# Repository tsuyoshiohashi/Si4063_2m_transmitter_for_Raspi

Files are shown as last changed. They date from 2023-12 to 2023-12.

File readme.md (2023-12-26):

# Si4063 2m transmitter for Raspi

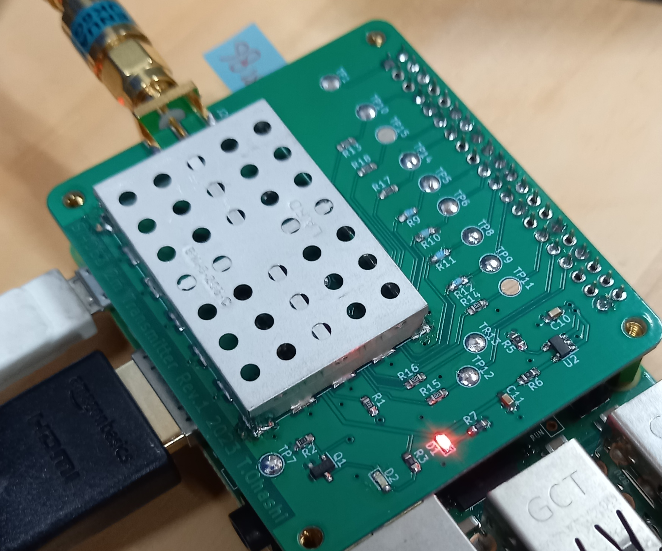
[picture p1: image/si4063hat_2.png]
Si4063_hat si4063_hat


Transmit a modulated wave in the 144Mhz band using RaspberryPi and an expansion board (si4063 2m radio hat, homemade, see hat directory).

・Frequency can be set from 144 to 146MHz

・The maximum output is 0.1W (20dBm) and can be set in 128 steps.

・CW (Continuous wave), OOK, FSK modulation is possible

・If you want to attach an antenna and actually emit radio waves, you will need an amateur radio license/qualification.

. When operating, be sure to terminate the SMA terminal (J2: RF output terminal). Otherwise, it may break.

# Environment where operation has been confirmed
Raspi3B+　Raspberry Pi OS(bookworm)

You need to install pigpio.

# HAT configuration and operation
As the title says, we use Silicon Labs' Si4063-C.

The SPI is controlled from the Raspi, but it is controlled by itself via GPIO, so there is no need to configure the SPI of the Raspi.
If SPI0 is enabled, please disable it. (Used as GPIO)

Si4063 operates in Direct Async Mode.

Transmission data is passed from the Raspi's GPIO to the Si4063's GPIO, and is transmitted at the same timing without going through the FIFO.

While transmitting, LED2 lights up as an indicator.

# Software
## si4063.py

You can perform simple sending operations by running it from the command line.

````
$ python si4063.py
````

If there are no arguments, display simple help and exit.
The arguments are as follows.

### -c (seconds)
Transmits unmodulated waves for the specified number of seconds. (10 seconds if not specified)
It is used to measure output magnitude, spurious, etc.

The transmission frequency is 144.05MHz by default. (Can be set with variables)

### -f
Transmits FSK modulated wave for about 10 seconds.

The data is 10101010....
The data rate is approximately 1000bps.
The frequency deviation is 8kHz.
These can be set with parameters.

The IC specifications support data rates up to 1Mbps.
I think high-speed communication is possible if you create an accurate baud rate using a timer interrupt. (It's a little difficult in python...)

### -o
Transmits OOK modulated wave for about 10 seconds.

The data is 10101010....
The data rate is approximately 1000bps.
Like FSK, it can be set with parameters.

Please note that si4063const.py is a parameter file. Please put it in the same directory.

## Main methods
si4063.py can be used by importing it into a python program as a module. (This is the original usage)

The main methods are shown below.

### reset()
Reset si4063.
Execute once after turning on the power.

### power_up()
Boot si4063. Use in the order of reset → power_up.

### part_info()
Get the chip number.
````
count, chip_no = si4063.part_info()
````
count: Number of times it took to retrieve (usually it can be read in one time, but if it is too many times, something is happening)

chip_no: Chip number (0x4063)

### set_radio_frequency(frequency)
Set the transmission frequency. The unit is Hz.
There may be an discrepancies of about 2Hz depending on the resolution of the synthesizer.

### set_modem_freq_offset(freq_offset)
Gives an offset to the transmit frequency.
This corrects the error in the crystal's oscillation frequency, but the value seems to vary depending on the modulation method.
The unit is Hz.

### set_pa_pwr_lvl(pwr_lvl)
Set the transmit power. Specify a value between 0x0 and 0x7f.
A graph of setting values and output can be found in Figure 8 of the si4063-C data sheet.

### setup(mod_type, freq_dev)
Configure the IC register settings and set the modulation method.

Specify either MOD_TYPE_OOK, MOD_TYPE_FSK, or MOD_TYPE_CW.

For FSK, the frequency deviation can be specified in Hz.

### start_tx()
Start sending.

### stop_tx()
Stop sending. The internal state is READY.

### tx_data(data)
Set the sending data data(0|1).
In the sending state, it will be reflected immediately.

### get_adc_reading()
Measures the IC power supply voltage and temperature.

````
temp, voltage = si4063.get_adc_reading()
````

The units are °C and V.

Please note that si4063Cconst.py is a parameter file. Please put it in the same directory.

## radio_morse.py

This is a sample app that sends Morse code.
Import and use si4063.py.

Start it by specifying the wpm number as an argument on the command line.

````
$ python radio_morse.py wpm
````

You will be asked to enter a character string, so please enter an alphanumeric character string.

Morse code '.' and '-' are displayed on the console and sent.

Please note that wpm is limited to 5 to 30.

Have A Fun!

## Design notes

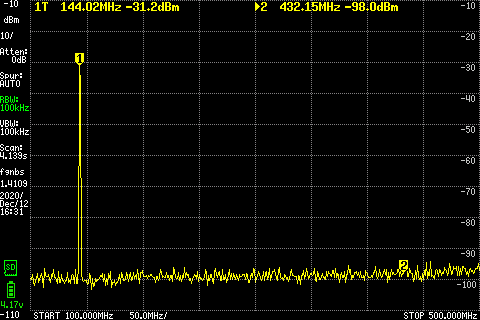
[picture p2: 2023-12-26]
image/si4063_harmonics.bmp

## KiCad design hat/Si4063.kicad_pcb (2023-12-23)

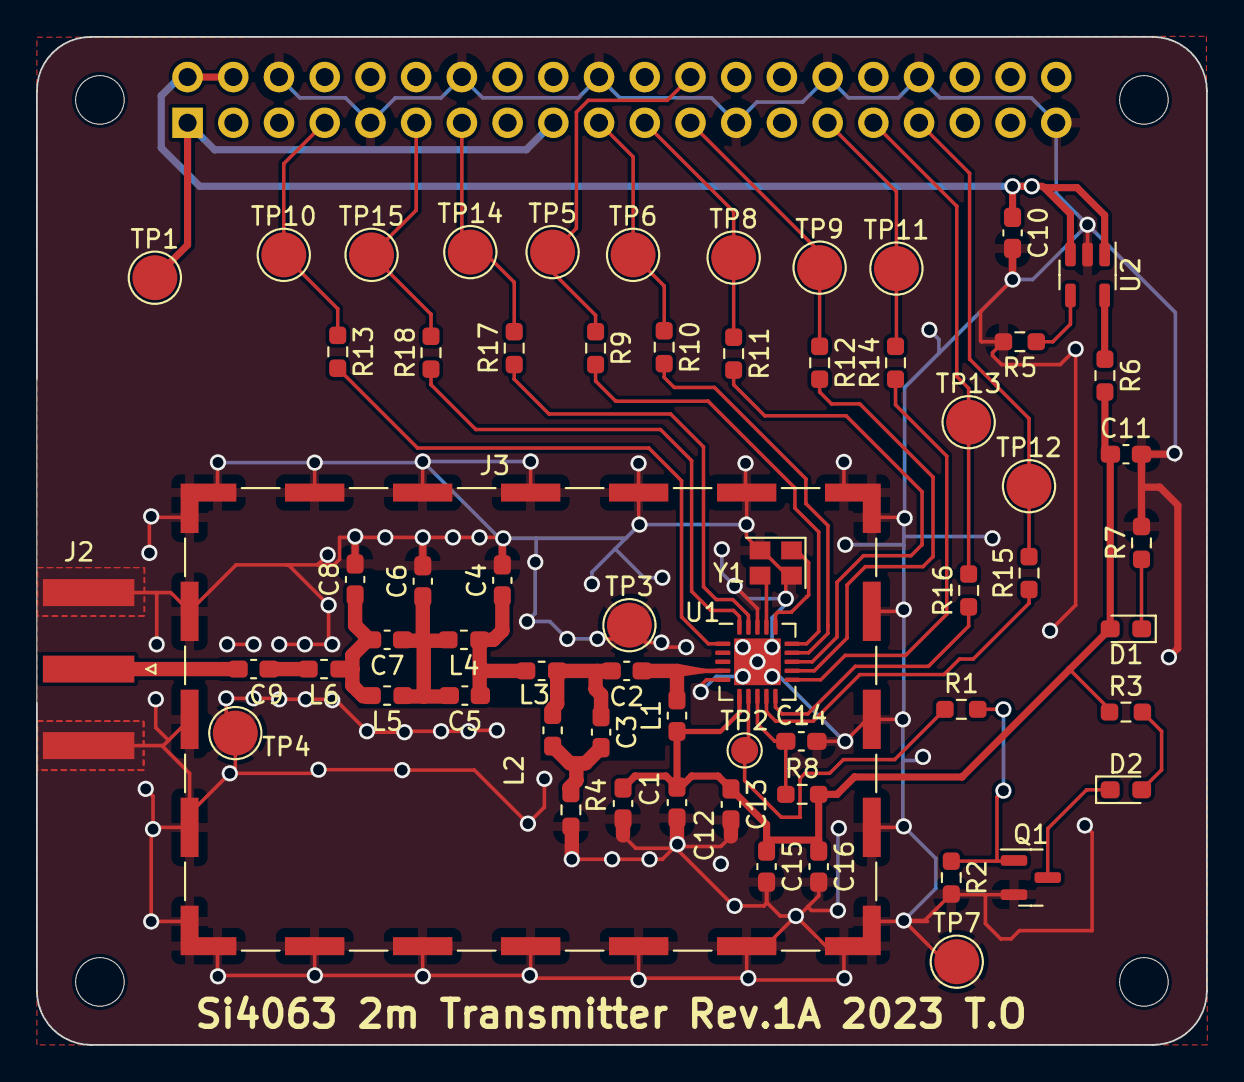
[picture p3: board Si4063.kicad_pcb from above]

Board: 2 copper layers, 65.0 x 56.0 mm, 68 parts (1 on the bottom side), 42 nets.

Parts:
C7: 2.4pF; C_0603_1608Metric_Pad1.08x0.95mm_HandSolder
C10, C11: 105; C_0603_1608Metric_Pad1.08x0.95mm_HandSolder
C12: 101; C_0603_1608Metric_Pad1.08x0.95mm_HandSolder
C13: 471; C_0603_1608Metric_Pad1.08x0.95mm_HandSolder
C14, C15: 104; C_0603_1608Metric_Pad1.08x0.95mm_HandSolder
C16: 225; C_0603_1608Metric_Pad1.08x0.95mm_HandSolder
C?: 471; C_0603_1608Metric_Pad1.08x0.95mm_HandSolder
C?#2, C?#3: 22pF; C_0603_1608Metric_Pad1.08x0.95mm_HandSolder
C?#4, C?#5: 13pF; C_0603_1608Metric_Pad1.08x0.95mm_HandSolder
C?#6, C?#8: 470pF; C_0603_1608Metric_Pad1.08x0.95mm_HandSolder
C?#7: 3.6pF; C_0603_1608Metric_Pad1.08x0.95mm_HandSolder
D1: PWR; D_0603_1608Metric_Pad1.05x0.95mm_HandSolder
D?: LED; D_0603_1608Metric_Pad1.05x0.95mm_HandSolder
J1: GPIO; PinSocket_2x20_P2.54mm_Vertical
J2: Conn_Coaxial; SMA_Amphenol_132289_EdgeMount
J3: RFShield_TwoPieces; Laird_Technologies_BMI-S-205-F_38.10x25.40mm
L?: 100nH; L_0603_1608Metric_Pad1.05x0.95mm_HandSolder
L?#2: 390nH; L_0603_1608Metric_Pad1.05x0.95mm_HandSolder
L?#3, L?#6: 56nH; L_0603_1608Metric_Pad1.05x0.95mm_HandSolder
L?#4: 82nH; L_0603_1608Metric_Pad1.05x0.95mm_HandSolder
L?#5: 33nH; L_0603_1608Metric_Pad1.05x0.95mm_HandSolder
MH1, MH2, MH3, MH4: MountingHole_2.7mm_M2.5
Q?: Q_NMOS_GSD; SOT-23
R5, R6: 0; R_0603_1608Metric_Pad0.98x0.95mm_HandSolder
R7: 391; R_0603_1608Metric_Pad0.98x0.95mm_HandSolder
R8: 4R7; R_0603_1608Metric_Pad0.98x0.95mm_HandSolder
R9, R13, R14, R15, R16, R17, R18: 47; R_0603_1608Metric_Pad0.98x0.95mm_HandSolder
R10, R11, R12: 39; R_0603_1608Metric_Pad0.98x0.95mm_HandSolder
R?: 2.2k; R_0603_1608Metric_Pad0.98x0.95mm_HandSolder
R?#2: 10k; R_0603_1608Metric_Pad0.98x0.95mm_HandSolder
R?#3: 271; R_0603_1608Metric_Pad0.98x0.95mm_HandSolder
R?#4: 50; R_0603_1608Metric_Pad0.98x0.95mm_HandSolder
TP1: 3.3V; TestPoint_Pad_D2.5mm
TP3, TP4, TP7: GND; TestPoint_Pad_D2.5mm
TP5: nSEL; TestPoint_Pad_D2.5mm
TP6: SDI; TestPoint_Pad_D2.5mm
TP8: SDO; TestPoint_Pad_D2.5mm
TP9: SCLK; TestPoint_Pad_D2.5mm
TP10: SDN; TestPoint_Pad_D2.5mm
TP11: nIRQ; TestPoint_Pad_D2.5mm
TP12: GPIO0; TestPoint_Pad_D2.5mm
TP13: GPIO1; TestPoint_Pad_D2.5mm
TP14: GPIO2; TestPoint_Pad_D2.5mm
TP15: GPIO3; TestPoint_Pad_D2.5mm
TP?: TestPoint; TestPoint_Pad_D1.5mm
U1: Si4063; QFN-20-1EP_4x4mm_P0.5mm_EP2.6x2.6mm
U2: MIC5365-3.3YD5; SOT-23-5
Y1: 30MHz; Crystal_SMD_2520-4Pin_2.5x2.0mm

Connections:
+3.3VA: C11.1, C12.1, C13.1, C15.1, C16.1, C?.1, D1.2 (A), L?#2.1, R6.2, R8.2, R?#3.1, U1.6 (VDD)
+5V: C10.1, J1.2, J1.4, U2.1 (VIN), U2.3 (EN)
/GPIO4_SDN: J1.7, R13.1, TP10.1
/GPIO5_nIRQ: J1.29, R14.2, TP11.1
/GPIO6_GPIO1: J1.31, R16.2, TP13.1
/GPIO13_GPIO0: J1.33, R15.2, TP12.1
/GPIO17_GPIO3: J1.11, R18.2, TP15.1
/GPIO27_GPIO2: J1.13, R17.2, TP14.1
/SPI0.CE0: J1.24, R9.1, TP5.1
/SPI0.MISO: J1.21, R11.1, TP8.1
/SPI0.MOSI: J1.19, R10.1, TP6.1
/SPI0.SCLK: J1.23, R12.1, TP9.1
/power/LED_3.3: D1.1 (K), R7.1
/rf/RF_OUT: C?#8.2, J2.1 (In)
GND: C10.2, C11.2, C12.2, C13.2, C14.2, C15.2, C16.2, C?.2, C?#2.2, C?#3.2, C?#4.2, J1.6, J1.9, J1.14, J1.20, J1.25, J1.30, J1.34, J1.39, J2.2 (Ext), J3.1 (Shield), Q?.2 (S), R5.2, R7.2, R?#2.2, R?#4.2, TP3.1, TP4.1, TP7.1, U1.5 (NC), U1.18 (GND), U1.21 (PADDLE), U2.2 (GND), Y1.2, Y1.4
unnamed: C?#6.1, L?#2.2, U1.4 (TX)
unnamed: C?#5.1, C?#6.2, L?.1, L?#3.1
unnamed: C?#5.2, L?.2, R?#4.1
unnamed: C?#3.1, C?#7.1, L?#3.2, L?#4.1
unnamed: C7.1, C?#2.1, C?#7.2, L?#4.2, L?#6.1
unnamed: C7.2, C?#4.1, L?#5.1, L?#6.2
unnamed: C?#8.1, L?#5.2
unnamed: C14.1, R8.1, U1.8 (VDD)
unnamed: D?.1 (K), Q?.3 (D)
unnamed: D?.2 (A), R?#3.2
unnamed: J1.1, J1.17, TP1.1
unnamed: Q?.1 (G), R?.2, R?#2.1
unnamed: R?.1, TP?.1, U1.7 (TXRAMP)
unnamed: R5.1, U2.4 (NC)
unnamed: R6.1, U2.5 (VOUT)
unnamed: R9.2, U1.15 (nSEL)
unnamed: R10.2, U1.14 (SDI)
unnamed: R11.2, U1.13 (SDO)
unnamed: R12.2, U1.12 (SCLK)
unnamed: R13.2, U1.1 (SDN)
unnamed: R14.1, U1.11 (nIRQ)
unnamed: R15.1, U1.9 (GPIO0)
unnamed: R16.1, U1.10 (GPIO1)
unnamed: R17.1, U1.19 (GPIO2)
unnamed: R18.1, U1.20 (GPIO3)
unnamed: U1.16 (XOUT), Y1.1
unnamed: U1.17 (XIN), Y1.3

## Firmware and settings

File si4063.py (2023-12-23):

#!/usr/bin/env python3
#
# si4063.py
# driver fot raspi si4063 2m radio hat(my own work, see hat directory)
# 
# This implementation is for personal experiments.
# Copyright (c) 2023 Tsuyoshi Ohashi
# Released under the MIT license
# https://opensource.org/licenses/mit-license.php
#
# references
# https://github.com/thasti/utrak
# https://www.silabs.com/documents/public/application-notes/AN633.pdf
# https://www.silabs.com/documents/public/application-notes/EZRadioPRO_REVC2_API.zip
#
# CHIP DATA MODE : DIRECT ASYNCHRONOUS SOURCE MODE
import pigpio
import time
from si4063const import *

__version__ = "2023.12.23"

# debug flag
debug = False
#debug flag primitive
_debug = False

class Si4063:
    # configure raspi pins
    # I/O and SOFTWARE SPI
    def __init__(self):
        self.pi = pigpio.pi()
        if not self.pi.connected:
            raise Exception("Error: pigpio NOT connected")
        
        # Shutdown pin
        self.pi.set_mode(GPIO_SHDN, pigpio.OUTPUT)
        self.pi.write(GPIO_SHDN, 1)  # PIN_SHDN = High

        # GPIO_13 OUTPUT for TXDATA  
        self.pi.set_mode(GPIO_TX_DATA, pigpio.OUTPUT)
        self.pi.write(GPIO_TX_DATA, 0)  # TX_DATA = Low

        # GPIO_6 INPUT for CTS
        self.pi.set_mode(GPIO_CTS, pigpio.INPUT)
        self.pi.set_pull_up_down(GPIO_CTS, pigpio.PUD_DOWN)

        # nSEL pin
        self.pi.set_mode(GPIO_nSEL, pigpio.OUTPUT)
        self.pi.write(GPIO_nSEL, 1)  # nSEL = 1
        # SDI(MOSI) pin
        self.pi.set_mode(GPIO_SDI, pigpio.OUTPUT)
        self.pi.write(GPIO_SDI, 0)  # MOSI = 0
        # SDO(MISO) pin
        self.pi.set_mode(GPIO_SDO, pigpio.INPUT)
        self.pi.set_pull_up_down(GPIO_SDO, pigpio.PUD_DOWN) # pull down
        # SCLK pin
        self.pi.set_mode(GPIO_SCLK, pigpio.OUTPUT)
        self.pi.write(GPIO_SCLK, 0)  # SCLK = 0
    
    # Set nSEL pin Low
    def _spi_select(self):
        if(_debug):
            print("\t_select")
        self.pi.write(GPIO_nSEL, 0)
    # Set nSEL pin High
    def _spi_deselect(self):
        if(_debug):
            print("\t_deselect")
        self.pi.write(GPIO_nSEL, 1)
    # Set SCLK pin 1/0
    def _spi_clk(self, bit):
        self.pi.write(GPIO_SCLK, bit)
    
    # Write a byte
    def _spi_wr(self, data):
        if(_debug):
            print("\t_wr: {:02x}".format(data))
        for i in range(8):
            self._spi_clk(0)
            bit = 1 if((data<<(i) & 0x80)) else 0
            self.pi.write(GPIO_SDI, bit)
            self._spi_clk(1)
            
        self._spi_clk(0)
        self.pi.write(GPIO_SDI, 0)  
    
    # Read a byte
    # return : 1 byte read
    def _spi_rd(self):
        data = 0
        for i in range(8):
            self._spi_clk(0)
            data = data<<1
            self.pi.write(GPIO_SDI, 1)      # write 0xff in read
            bit = self.pi.read(GPIO_SDO)
            data += bit
            self._spi_clk(1)
        
        self._spi_clk(0)
        if(_debug):
            print("\t_rd: {:02x}".format(data))
        return data
        
    # Check CTS pin
    # return : cts(0xff or 0x00=timeout)
    def _is_CTS(self):
        timeout, cts = 1000, 0x00

        while(timeout>=0):
            bit_cts = self.pi.read(GPIO_CTS)
            if(bit_cts==1):
                cts = 0xff    
                break
            time.sleep(0.001)
            timeout -=1
        return cts
    
    # Check CTS over SPI
    # rturn : CTS(0xff), Not deselect to continue
    #         0x00,  deselect 
    def _is_CTS_spi(self):
        timeout, cts = 10, 0x00

        while(timeout>=0):
            self._spi_select()
            self._spi_wr( CMD_READ_CMD_BUFF)
            cts = self._spi_rd()
            if(cts==0xff):
                break
            self._spi_deselect()
            time.sleep(0.001)
            timeout -=1
        return cts      
    
    # Write bytes after wait CTS
    # to_send : bytes to be written
    def _write(self, to_send, desel=True):
        if(_debug):
            print("\t_Write:")
        
        #self._wait_cts(read_reply=False)
        self._is_CTS()
        self._spi_select()
        for b in to_send:
            b_as_bytes = b.to_bytes(1,byteorder="big")
            #self._wait_cts(False)
            self._spi_wr(b)
        if(desel):
            self._spi_deselect()

    # Read count size bytes after select and check CTS
    # 
    # count : qty of read data
    # desel :  deselect after read data
    # return : byte(s) read (list)
    def _read(self, count, desel=True):
        if(_debug):
            print("\t_Read:")
        self._is_CTS()
        self._spi_select()
        reply = []
        self._spi_wr(CMD_READ_CMD_BUFF)       
        for i in range(count):
            #self._wait_cts(read_reply=False)
            reply.append( self._spi_rd())           
        if(desel):
            self._spi_deselect()
        return reply
    
    # Enter Shutdown State
    def shutdown(self):
        self.pi.write(GPIO_SHDN, 1)     # PIN_SHDN = High
        time.sleep(0.001)              # Wait 100μS

    # Exit Shutdown State
    def wakeup(self):
        self.pi.write(GPIO_SHDN, 0)     # PIN_SHDN = Low
        time.sleep(0.02)                # Wait 20mS
        #self._wait_cts(read_reply=0)
        self._is_CTS()

    # Reset chip, shutdown and wake-up
    def reset(self):
        self.shutdown()
        self.wakeup()
    
    # NOP,ensure communication established
    # return : CTS(0xff or 0x00)
    def nop(self):
        self._is_CTS()
        self._spi_select()
        self._spi_wr(CMD_NOP)
        ret = self._spi_rd()
        if(debug):
            print("Nop: {:02x}".format(ret))
        self._spi_deselect()
        #self._wait_cts(False)
        return ret
        
    # power-up(boot) and set XTAL freq
    def power_up(self):
        if(debug):
            print("power_up")
        #self._wait_cts(read_reply=False)
        self._is_CTS()
        FUNC = 1    # EZRadio PRO
        TCXO = 0    # 0=XTAL, 1=ext TCXO
        
        to_send = [CMD_POWER_UP, FUNC, TCXO, 0xff & (FREQ_XTAL >> 24), 0xff & (FREQ_XTAL >> 16), 0xff & (FREQ_XTAL >> 8), 0xff & FREQ_XTAL]
        if(debug):
            print("to_send: ", ' '.join('{:02x}'.format(x) for x in to_send))
        self._write(to_send)

        time.sleep(0.01)
        #self._wait_cts(read_reply=False)
        self._is_CTS()

     # Get device info(Chip No)
     # return : count: number of times tried to read, chip_no: chip number(0x4063)
    def part_info(self):
        if(debug):
            print("part_info")
        chip_no = None
        
        self._is_CTS()
        time.sleep(0.01)
        
        self._spi_select()
        self._spi_wr(CMD_PART_INFO)
        self._spi_deselect()
        
        count = 1
        while(count<10):
            part_info = self._read(1+8, desel=True)
            if(part_info[0]==0xff):
                chip_no = (part_info[2]<<8) + part_info[3]
                if(debug):
                    print("Part_info: ", ' '.join('{:02x}'.format(x) for x in part_info))
                    print("Chip No : {:04x}".format(chip_no))
                break  
            else:
                time.sleep(0.1)
                count += 1
       
        return count, chip_no

    # Read and Convert temperature and battery voltage 
    # return : temprature, battery voltage
    def get_adc_reading(self):
        if(debug):
            print("get_adc_reading")
        #self._wait_cts(read_reply=False)
        cmd = CMD_GET_ADC_READING
        adc_en = (1<<4) | (1<<3) | (0<<2) | 0 # temperature, battery voltage, adc_gpio, adc_pin
        adc_cfg = 0x00  # Use defaults
        to_send = [cmd, adc_en, adc_cfg]
        self._write( to_send, desel=True)
        time.sleep(0.02)     # wait conversion

        reply = self._read(1+6, desel=True)
        #if(debug):
        #    print("ADC Reply: ", ' '.join('{:02x}'.format(x) for x in reply))

        if(reply[0]==0xff):
            # battery voltage
            battery_adc = (reply[3]<<8) + reply[4]        
            battery_voltage = 3*battery_adc / 1280
            if(debug):
                #print("Batt adc : {:04x}".format(battery_adc ))
                print("Battery Voltage: ", battery_voltage)
            # temprature
            temp_adc = (reply[5]<<8) + reply[6]        
            temp = (899 / 4096) * temp_adc - 293
            if(debug):
                #print("Temp adc : {:04x}".format(temp_adc ))
                print("Temprature: ", temp)
        else:
            temp, battery_voltage = None, None
        return temp, battery_voltage
    
    # Request Device State
    # return : current state
    def request_device_state(self):
        if(debug):
            print("request_device_state")
        #self._wait_cts(read_reply=False)
        self._is_CTS()
        time.sleep(0.01)
        self._spi_select()
        self._spi_wr(CMD_REQUEST_DEVICE_STATE)
        self._spi_deselect()
        
        #self._wait_cts(read_reply=True)
        dev_state = self._read(1+2, desel=True)
        if(dev_state[0]==0xff):
            #self._wait_cts(read_reply=True)
            cur_state = dev_state[1]
        else:
            cur_state = None
        if(debug):
            print("Main State: ", ' '.join('{:02x}'.format(x) for x in dev_state))
        return cur_state
    
    # Change State in State Machine
    # next_state : next state to be
    def change_state(self, next_state):
        cmd = CMD_CHANGE_STATE
        to_send = [cmd, next_state]
        self._write(to_send)
        if(debug):
            print("to_send: ", ' '.join('{:02x}'.format(x) for x in to_send))
    
    # Set a value of property
    # group : group number of property
    # index : proterty index
    # val : value to be set
    def set_property(self, group, index, val):
        command = CMD_SET_PROPERTY
        to_send = [command, group, 1, index, val]
        if(debug):
            print("Set_prop TO_SEND: ", ' '.join('{:02x}'.format(x) for x in to_send))
        self._write(to_send)
    
    # Set  values of property
    # group : group number of property
    # index : proterty index
    # vals : values to be set (list)
    def set_properties(self, group, index, vals):
        command = CMD_SET_PROPERTY
        length = len(vals)
        to_send = [command, group, length] + [index] + vals
        if(debug):
            print("Set_prop TO_SEND: ", ' '.join('{:02x}'.format(x) for x in to_send))
        #self._wait_cts(reply=False)
        self._write(to_send)
        #self._wait_cts(read_reply=False)     
    
    # Get a value of property(s)
    # prop : list, [group, index, num of property]
    # return : value(s) of property (list)
    def get_property(self, prop):
        to_send = [CMD_GET_PROPERTY, prop[0], prop[2], prop[1]]
        if(debug):
            print("Get_prop TO_SEND: ", ' '.join('{:02x}'.format(x) for x in to_send))
        self._write(to_send)
        time.sleep(0.01)
        reply = self._read( 1 + prop[2])
        if(debug):
            print("prop(s): ", ' ', ' '.join('{:02x}'.format(x) for x in reply))
        return reply[1:]
    
    # Set Xtal frequency tuning 
    def set_global_xo_tune(self):
        group, index = GLOBAL_XO_TUNE[0], GLOBAL_XO_TUNE[1]
        tune_value = 0x40       # High=7f, Low=0
        global_xo_tune = 0x7f & tune_value  # 7bits
        self.set_property(group, index, global_xo_tune)

    # Chip Operation mode setting
    def set_global_config(self):
        group, index = GLOBAL_CONFIG[0], GLOBAL_CONFIG[1]
        reserved = 0x01
        fast = 1    # quick start_tx
        fifo = 0    # split
        generic = 0 # generic protocol
        high_perf = 0  # 0=high performance TX and RX, 1=Low power mode TX and RX
        global_cfg = 0xff & ((reserved << 6) | (fast << 5) | (fifo << 4) | (generic <<1) | high_perf)
        self.set_property(group, index, global_cfg)

    # Interrupt setting
    def set_int_ctl_enable(self):
        group, index = INT_CTL_ENABLE[0], INT_CTL_ENABLE[1]
        chip_int = 0    # 0=DISABLED, 1=ENABLED
        ph_int = 0
        int_ctrl = chip_int<<2 | ph_int
        self.set_property(group, index, int_ctrl)
        
    # disable tx preamble
    def set_preamble_tx_length(self):
        group, index = PREAMBLE_TX_LENGTH[0], PREAMBLE_TX_LENGTH[1]
        tx_length = 0
        self.set_property(group, index, tx_length)

    # No transmit sync word
    def set_sync_config(self):
        group, index = SYNC_CONFIG[0], SYNC_CONFIG[1]
        sync_cfg = 0xff & (1 << 7 )  # NO_SYNC_XMIT
        self.set_property(group, index, sync_cfg)

    # Select modulation type and source (CW/OOK/FSK, ASYNC Direct mode)
    def set_modem_mod_type_direct(self, type_mod):
        group, index = MODEM_MOD_TYPE[0], MODEM_MOD_TYPE[1]
        tx_direct_mod_type = (DIRECT_MOD_TYPE_ASYNC<<7)     # 1=ASYNC, 0=SYNC
        tx_direct_mod_gpio = (0<<5)     # 0=GPIO0
        mod_source = (MOD_SOURCE_DIRECT <<3)            # 1=DIRECT, 2=PSEUDO, 0=PACKET
        if(type_mod<MOD_TYPE_CW or type_mod>MOD_TYPE_FSK):
            raise Exception("Error: MOD_TYPE")
        mod_type = 0xff & (tx_direct_mod_type | tx_direct_mod_gpio | mod_source | type_mod)
        self.set_property(group, index, mod_type)
    
    # Set Data Rate
    def set_modem_data_rate(self, data_rate):
        group, index = MODEM_DATA_RATE[0], MODEM_DATA_RATE[1]
        props = [0xff & (data_rate>>16), 0xff & (data_rate>>8), 0xff & data_rate]
        self.set_properties(group, index, props)
        
    # Setup NCO modulo and oversampling mode
    def set_modem_tx_nco_mode(self):
        group, index = MODEM_TX_NCO_MODE[0], MODEM_TX_NCO_MODE[1]   # 0x06..0x09
        txosr = 0    # 0=ENUM_0 10x
        #
        # MODEM_TX_NCO_MODE = MODEM_DATA_RATE x FREQ_XTAL / (TX_DATA_RATE x TXOSR)
        # Here, Define MODEM_DATA_RATE = TX_DATA_RATE, TXOSR = 10
        ncomod = int(FREQ_XTAL / 10)
        props = [0xff & ((txosr <<2) | (ncomod>>24)), 0xff & (ncomod >>16), 0xff & (ncomod >>8), 0xff & ncomod]
        self.set_properties(group, index, props)
    
    # Set FSK Deviation
    def set_modem_freq_dev(self, freq_dev=8333):
        group, index = MODEM_FREQ_DEV[0], MODEM_FREQ_DEV[1]   # 0x0a..0x0c
        # MODEM_FREQ_DEV = 2^19 * outdiv * desired_dev_Hz / ( Npresc * freq_xo)
        # Here, outdiv = OUTDIV_2M, Npresc = 2,
        modem_freq_dev = round( 2**19 * OUT_DIV_2M * freq_dev / (2 * FREQ_XTAL))   # 2=High performance
        if(debug):
            print(freq_dev, modem_freq_dev)
        props = [0xff & (modem_freq_dev>>16), 0xff & modem_freq_dev>>8, 0xff & modem_freq_dev]
        self.set_properties(group, index, props)

    # Set offset frequency
    def set_modem_freq_offset(self, freq_offset):
        group, index = MODEM_FREQ_OFFSET[0], MODEM_FREQ_OFFSET[1]   # 0x0d..0x0e
        # MODEM_FREQ_OFFSET = 2^19 * outdiv * desired_offset_Hz / ( Npresc * freq_xo)
        # Here, outdiv = OUTDIV_2M, Npresc = 2,
        modem_freq_offset = round( 2**19 * OUT_DIV_2M * freq_offset / (2 * FREQ_XTAL))   # 2=High performance
        props = [0xff & modem_freq_offset>>8, 0xff & modem_freq_offset]
        self.set_properties(group, index, props)

    # Set chip High performance and 2m band
    def set_modem_clkgen_band(self):
        group, index = MODEM_CLKGEN_BAND[0], MODEM_CLKGEN_BAND[1]
        sy_recal = 1<<4         # SKIP FORCE_SY_RECAL
        sy_sel = DIV_BY_2<<3      # 1=Div-by-2,High performance
        #band = FVCO_DIV_8    # 2=FVCO_DIV_8(3.6GHz/8=450MHz)
        band = FVCO_DIV_24    # 5=FVCO_DIV_24(3.6GHz/24=150MHz)
        modem_clkgen_band = sy_recal | sy_sel | band
        self.set_property(group, index, modem_clkgen_band)
        
    # Enable TX Ramp Signal and Set pa_mode HP_COARSE/SQW
    def set_pa_mode(self):
        group, index = PA_MODE[0], PA_MODE[1]
        ext_pa_ramp = EXT_TX_RAMP_EN<<7     # 1=Enable, 0=Disable tx ramp signal
        pa_sel = HP_COARSE<<2           # 2=HP_COARSE, 1=HP_FINE, 6=LowPower(Si4460), 8=MidPower(Si4461)
        #pa_sel = HP_FINE<<2           # 2=HP_COARSE, 1=HP_FINE, 6=LowPower(Si4460), 8=MidPower(Si4461)
        pa_mode = ext_pa_ramp | pa_sel  # bit0 0=Class-E/Square Wave match, 1=Switched Current Mode
        self.set_property(group, index, pa_mode)  # SQW
    
    # Configure PA output level (ddac = 0x0:min - 0x7f:max)
    def set_pa_pwr_lvl(self, ddac):
        group, index = PA_PWR_LVL[0], PA_PWR_LVL[1]
        pwr_lvl = 0x7f & ddac
        self.set_property(group, index, pwr_lvl)
        
    # Set PA duty cycle and bias current
    def set_pa_bias_clkduty(self, ob=0x0):
        group, index = PA_BIAS_CLKDUTY[0], PA_BIAS_CLKDUTY[1]
        clk_duty = CLKDUTY_DIFF_50 << 6    # 3=SINGLE_25, 0=DIFF_50
        #ob = 0x3f           # When Switched Current Mode
        bias_clkduty = 0xff & (clk_duty | ob)
        self.set_property(group, index, bias_clkduty)
    
    # Set frequency (now 2m band only)
    def set_radio_frequency(self, freq):
        debug = 0
        # Check Frequency Range
        if(debug):
            print("set_radio_frequency")
        if (freq < 144e6) or (freq > 146e6):
            raise Exception("Error: ", sys._getframe().f_code.co_name)
        ### Set Integer Divider
        group, index = FREQ_CONTROL_INTE[0], FREQ_CONTROL_INTE[1]
        outdiv = OUT_DIV_2M     # 145MHz band
        f_int_2m = 2 * FREQ_XTAL / outdiv
        f_int = int(freq / f_int_2m) - 1       # f_frac must be between 1 and 2
        self.set_property(group, index, f_int)
        ### Set Fractinal Divider
        group, index = FREQ_CONTROL_FRAC[0], FREQ_CONTROL_FRAC[1]
        f_frac = round((freq / f_int_2m - f_int) * 2**19)        
        frac19 = 0xff & (f_frac >>16)
        frac15 = 0xff & (f_frac >>8)
        frac7 = 0xff & (f_frac)
        props = [frac19, frac15, frac7]
        self.set_properties(group, index, props)

        f_out = (f_int + f_frac/2**19) * 2 * FREQ_XTAL / outdiv
        if(debug):
            print("int: {}, frac: {}".format(f_int, f_frac))
            print("props:", ' '.join('{:02x}'.format(x) for x in props))
            print("ratio(1<2): ", f_frac/2**19)
            print("freq: {}, fout: {}".format(freq, f_out))
            self.get_property(FREQ_CONTROL_INTE)
            self.get_property(FREQ_CONTROL_FRAC)

    # Set OOK / Direct mode
    def set_mod_ook(self):
        self.set_modem_mod_type_direct(MOD_TYPE_OOK)
        
    # Set FSK / Direct mode
    def set_mod_fsk(self):
        self.set_modem_mod_type_direct(MOD_TYPE_FSK, freq_dev)
    
    # Select feed forward charge pump current
    def set_synth_pfdcp_cpff(self):
        group, index = SYNTH_PFDCP_CPFF[0], SYNTH_PFDCP_CPFF[1]
        cp_ff_cur = 0x0
        pfdcp_cpff = cp_ff_cur 
        self.set_property(group, index, pfdcp_cpff)
        
    #
    # Select integration charge pump current
    def set_synth_pfdcp_cpint(self):
        group, index = SYNTH_PFDCP_CPINT[0], SYNTH_PFDCP_CPINT[1]
        cp_int_cur = 0x0    # 40
        pfdcp_cpint = cp_int_cur 
        self.set_property(group, index, pfdcp_cpint)
    
    # Set gain scaling factors(Kv)
    def set_synth_vco_kv(self):
        group, index = SYNTH_VCO_KV[0], SYNTH_VCO_KV[1]
        ### [1,1] works well ###
        kv_dir = 0x1    # 1=half, 2=max
        kv_int = 0x1    # 1=33percent, 2=66percent 3=max
        vco_kv = kv_dir<<2 + kv_int 
        self.set_property(group, index, vco_kv)        
        
    # Initialize si4063 registers. Called After Power-up
    # type_mod : modulation type, CW/OOK/FSK
    # freq_dev : FSK frequency deviation Hz
    def setup(self, type_mod, freq_dev=8333):
        if(debug):
            print("Modulation : {}".format(type_mod))
        data_rate = 64000   # DUMMY in Direct Async mode
        self.set_global_config()
        self.set_global_xo_tune()
        
        self.set_int_ctl_enable()
        
        self.set_preamble_tx_length()
        self.set_sync_config()
        
        self.set_modem_tx_nco_mode()
        self.set_modem_data_rate(data_rate)
        self.set_modem_mod_type_direct(type_mod)
        if(type_mod == MOD_TYPE_FSK):
            self.set_modem_freq_dev(freq_dev)
        self.set_modem_clkgen_band()    # Set 2m band 
        #
        bias = 0x0
        self.set_pa_bias_clkduty(bias)
        self.set_pa_mode()
        #ddac = 0x7f
        #self.set_pa_pwr_lvl(ddac)
        
        #self.set_synth_pfdcp_cpff()
        #self.set_synth_pfdcp_cpint()
        # uncomment the following if the frequency is unstable
        #self.set_synth_vco_kv()
    
    # set tx bit in direct mode
    def tx_data(self, bit):
        self.pi.write(GPIO_TX_DATA, bit & 0x01)  # TX_DATA
            
    # set tx bit toggled
    def tx_data_toggle(self):
        self.pi.write(GPIO_TX_DATA, not self.pi.read(GPIO_TX_DATA))  # TX_DATA
    
    # start transmit
    def start_tx(self):
        cmd = CMD_START_TX
        txcomplete_state = STATE_READY<<4   # 1=SLEEP, 2=SPI_ACTIVE, 3=READY
        start_timing = 0   # 0=immediate, 1=upon WUT
        condition = txcomplete_state + start_timing
        channel = 0
        tx_len = [0, 0]  # 0=Direct mode??
        to_send = [cmd, channel, condition, tx_len[1], tx_len[0], 0, 0]
        self._write(to_send)
        if(debug):
            print("to_send: ", ' '.join('{:02x}'.format(x) for x in to_send))        

    # stop transmit and set state READY
    def stop_tx(self):
        self.change_state(STATE_READY)

    # change state TX
    def enable_tx(self):
        if(debug):
            print(sys._getframe().f_code.co_name)
        self.change_state(STATE_TX)    
    
    # destructor
    def __del__(self):
        self.pi.stop()          # Stop handling pin
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

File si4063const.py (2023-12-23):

# si4063const.py
# parameters for Si4063.py

# Chip name
NAME_CHIPS = {0x4063}

# GPIO pin config
# si4063_name - BCM# - raspi_IO_pin#
GPIO0 = 13  # GPIO13 = pin33
GPIO1 = 6   # GPIO6 = pin31
GPIO2 = 27  # GPIO27 = pin13
GPIO3 = 17  # GPIO17 = pin11
GPIOSDN = 4 # GPIO4 = pin7
GPIOnIRQ = 5   # GPIO05 = pin29

# SoftSPI (NOT BCM system SPI)
GPIO_nSEL = 8   # GPIO8 = pin24
GPIO_SDI = 10    # GPIO10 = pin19
GPIO_SDO = 9    # GPIO9 = pin21
GPIO_SCLK = 11   # GPIO11 = pin23

# Config GPIO
GPIO_TX_DATA = GPIO0 
GPIO_CTS = GPIO1
GPIO_SHDN = GPIOSDN

# Commands
CMD_NOP = 0x00
CMD_PART_INFO = 0x01
CMD_POWER_UP = 0x02
CMD_SET_PROPERTY = 0x11
CMD_GET_PROPERTY = 0x12
CMD_GPIO_PIN_CFG = 0x13
CMD_REQUEST_DEVICE_STATE = 0x33
CMD_CHANGE_STATE = 0x34
CMD_READ_CMD_BUFF = 0x44
CMD_START_TX = 0x31
CMD_GET_ADC_READING = 0x14

# States
STATE_NOCHANGE = 0
STATE_SLEEP = 1
STATE_SPI_ACTIVE = 2
STATE_READY = 3
STATE_TX_TUNE = 5
STATE_TX = 7

# API
FREQ_XTAL = 30000000  # 30MHz

OUT_DIV_2M = 24     # 142-175MHz
OUT_DIV_70CM = 8    # 420-525MHz
FVCO_DIV_24 = 5     # 3.6GHz/24=150MHz
FVCO_DIV_8 = 2      # 3.6GHz/8 =450MHz

DIV_BY_2 = 1    # High performance
DIV_BY_4 = 0    # Low-pwer mode

HP_FINE = 1     # Lower power,fine step size, 4063?
HP_COARSE = 2   # High power, large step size, 4063?

EXT_TX_RAMP_DIS = 0 # disable ext tx ramp signal
EXT_TX_RAMP_EN = 1  # enable ext tx ramp signal

CLKDUTY_DIFF_50 = 0     # High-power(4463/4464)
CLKDUTY_SINGLE_25 = 3   # Low-poower(4460)

DIRECT_MOD_TYPE_ASYNC = 1
DIRECT_MOD_TYPE_SYNC = 0

MOD_SOURCE_DIRECT = 1
MOD_SOURCE_PSEUDO = 2
MOD_SOURCE_PACKET = 0

# Modulation types
MOD_TYPE_CW = 0
MOD_TYPE_OOK = 1
MOD_TYPE_2FSK = 2
MOD_TYPE_FSK = 2

# GPIO Mode (part)
PULL_CTL = 0x40     # bit6
GPIO_MODE_NOTHING = 0    # 
GPIO_MODE_TRISTATE = 1   #
GPIO_MODE_DRIVE0 = 2     # Low output
GPIO_MODE_DRIVE1 = 3     # High output
GPIO_MODE_INPUT = 4      # Input for TX DATA in Direct mode
GPIO_MODE_CTS = 8
GPIO_MODE_INV_CTS = 9   
GPIO_MODE_CMD_OVERLAP = 10
GPIO_MODE_SDO = 11
GPIO_MODE_POR = 12
GPIO_MODE_EN_PA = 15
GPIO_MODE_TX_DATA_CLK = 16
GPIO_MODE_IN_SPEEP = 28
GPIO_MODE_TX_STATE = 32
GPIO_MODE_LOW_BATT = 36

# Properties
#  Name = [Group, Index, Size]
GLOBAL_XO_TUNE = [0x00, 0x00, 1]
GLOBAL_CLK_CFG = [0x00, 0x01, 1]
GLOBAL_CONFIG = [0x00, 0x03, 1]

INT_CTL_ENABLE = [0x01, 0x00, 1]

PREAMBLE_TX_LENGTH = [0x10, 0x00, 1]

SYNC_CONFIG = [0x11, 0x00, 1]

MODEM_MOD_TYPE = [0x20, 0x00, 1]
MODEM_DATA_RATE = [0x20, 0x03, 3]
MODEM_TX_NCO_MODE = [0x20, 0x06, 4]
MODEM_FREQ_DEV = [0x20, 0x0a, 3]
MODEM_FREQ_OFFSET = [0x20, 0x0d, 2]
MODEM_CLKGEN_BAND = [0x20, 0x51, 1]

PA_MODE = [0x22, 0x00, 1]
PA_PWR_LVL = [0x22, 0x01, 1]
PA_BIAS_CLKDUTY = [0x22, 0x02, 1]

SYNTH_PFDCP_CPFF = [0x23, 0x00, 1]
SYNTH_PFDCP_CPINT = [0x23, 0x01, 1]
SYNTH_VCO_KV = [0x23, 0x02, 1]

FREQ_CONTROL_INTE = [0x40, 0x00, 1]
FREQ_CONTROL_FRAC = [0x40, 0x01, 3]

###

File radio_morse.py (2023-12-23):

#!/usr/bin/env python3
#
# radio_morse.py 
# transmit morse signal w/ raspi si4063 2m radio hat(my own work, see hat directory)
# 
# This implementation is for personal experiments.
# Copyright (c) 2023 Tsuyoshi Ohashi
# Released under the MIT license
# https://opensource.org/licenses/mit-license.php
# 
import si4063 as radio
import time
import sys

__version__ = "2023.12.23"

# morse code encode table
morse_code = {
    'A': '.-', 'B': '-...', 'C': '-.-.', 'D': '-..', 'E': '.',
    'F': '..-.', 'G': '--.', 'H': '....', 'I': '..', 'J': '.---',
    'K': '-.-', 'L': '.-..', 'M': '--', 'N': '-.', 'O': '---',
    'P': '.--.', 'Q': '--.-', 'R': '.-.', 'S': '...', 'T': '-',
    'U': '..-', 'V': '...-', 'W': '.--', 'X': '-..-', 'Y': '-.--',
    'Z': '--..', '0': '-----', '1': '.----', '2': '..---', '3': '...--',
    '4': '....-', '5': '.....', '6': '-....', '7': '--...', '8': '---..',
    '9': '----.', '.': '.-.-.-', ',': '--..--', '?': '..--..', '\'': '.----.',
    '!': '-.-.--', '/': '-..-.', '(': '-.--.', ')': '-.--.-', '&': '.-...',
    ':': '---...', ';': '-.-.-.', '=': '-...-', '+': '.-.-.', '-': '-....-',
    '_': '..--.-', '"': '.-..-.', '$': '...-..-', '@': '.--.-.'
}

# convert text to morse code
# text : text to encode
# return : morse code("." and "-")
def text_to_morse(text):
    morse = ''
    for char in text.upper():
        if char in morse_code:
            morse += morse_code[char] + ' '  # Add space after char
        elif char == ' ':  # Add partition
            morse += '/ '
    return morse

# Convert unit time from wpm
# wpm : words per minute(morse speed)
def calculate_unit_time(wpm):
    return 1200 / wpm  # 5 chars/word, unit_time/char=1/5×60×1000=1200/wpm Second

# transmit radio morse code
# dot_time : time for dot (Second)
# morse_code : morse code text ("." and "-") 
def morse_code_to_ook(dot_time, morse_code):
    si4063.start_tx()
    for symbol in morse_code:
        print(symbol, end="", flush=True)
        if symbol == '.':
            si4063.tx_data(1)
            time.sleep(dot_time)
            si4063.tx_data(0)
            time.sleep(dot_time)
        elif symbol == '-':
            si4063.tx_data(1)
            time.sleep(3 * dot_time)
            si4063.tx_data(0)
            time.sleep(dot_time)
        elif symbol == ' ':
            time.sleep(3 * dot_time)
    print("")
    si4063.stop_tx()

# Send morse code converted from text
# text : text to send
# wpm : words per minute(morse speed)
def send_morse(text, wpm=10):
    
    morse_code = text_to_morse(text)
    unit_time = calculate_unit_time(wpm)/1000
    #print("wpm: ", wpm)
    print("morse code: ", morse_code)

    morse_code_to_ook(unit_time, morse_code)
    
### 
if __name__ == "__main__":
    args = sys.argv
    # morse speed is between 5 and 30 
    try:
        wpm = int(args[1])
        if(wpm>30):
            wpm = 30
        elif(wpm < 5):
            wpm = 5 
    except:
        wpm = 10
        
    print("Radio Morse Starting  ver.", __version__)
    print("radio ver.", radio.__version__)
    print("wpm: ", wpm)
    si4063 = radio.Si4063()    
    si4063.reset()          # Shutdown and Wake-up
    
    # Check part info
    count, chip_no = si4063.part_info()
    dots_read = '.' * count
    if(chip_no in radio.NAME_CHIPS):
        print("Detected" + dots_read + " {:04x}".format(chip_no))
    else:
        raise Exception(dots_read + "Error: wrong chip name {:04x}".format(chip_no))
    
    si4063.power_up()
    temperature, voltage = si4063.get_adc_reading()
    print("Temperature: {:.1f} °C".format(temperature))
    print("Voltage: {:.2f} volt".format(voltage))
    
    # set frequency
    radio_frequency = 144050000
    si4063.set_radio_frequency(radio_frequency)
    print("frequency(Hz): ", radio_frequency)
    si4063.set_modem_freq_offset(-4000)
    
    # set RF power
    pwr_lvl = 0x7f      # up to 0x7f(max)
    si4063.set_pa_pwr_lvl(pwr_lvl)
    ### OOK mode
    si4063.setup(radio.MOD_TYPE_OOK)
    
    text = input("Input text to send: ")
    send_morse(text, wpm)
    del si4063
    ###
    # end or radio_morse.py

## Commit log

2023-12-23 1st commit
    [Si4063.kicad_pcb, Si4063.kicad_sch, power.kicad_sch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]
2023-12-27 add pcb info
